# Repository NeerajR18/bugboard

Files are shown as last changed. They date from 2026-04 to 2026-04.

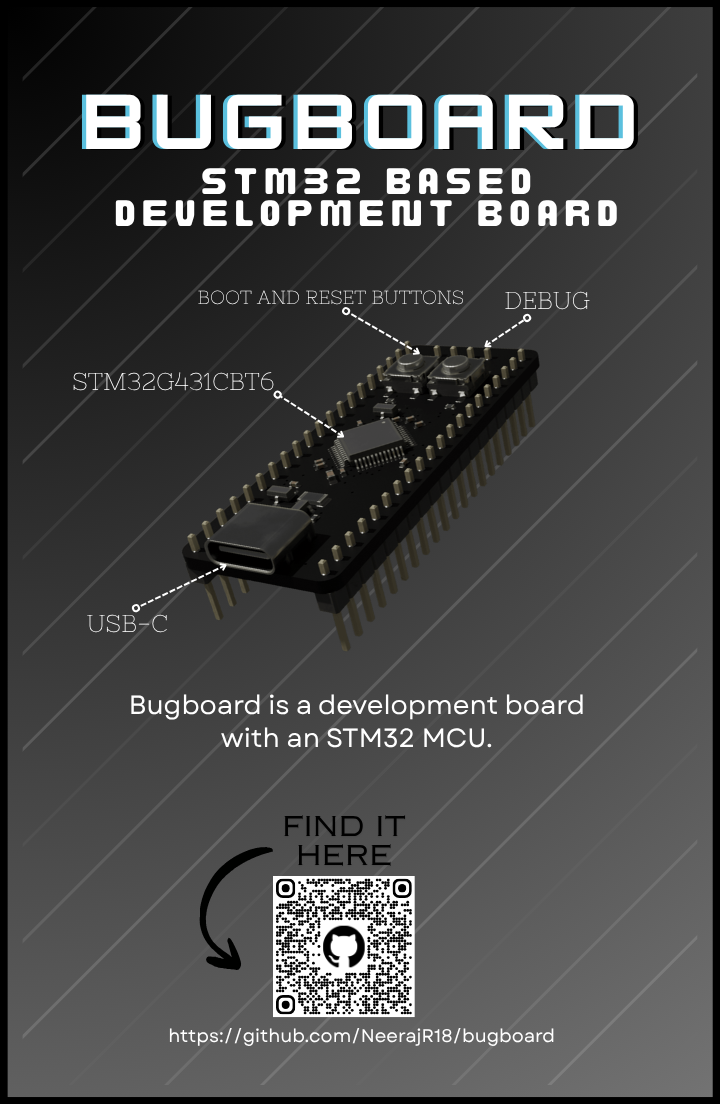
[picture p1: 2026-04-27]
Zine.png

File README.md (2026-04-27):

Zine

# bugboard
STM32 Based Development Board

Note : - This is still a work in progress.

bugboard is a development board with the STM32G431CBT6 as its core. 

This development board is intended to be used in a keyboard PCB. 

# Features

- STM32G431CBT6
- Built-in USB-C Port
- Small size design

# What is a development board?

A development board is a PCB (Printed Circuit Board) with an MCU along with other components such as a USB port, crystals etc. to make prototyping and designing circuits easier.
Since it already has certain components, it can be used directly in many circuits to save cost as well as time.
Development boards can vary in size, components, MCU type, amount of GPIOs etc.

bugboard, has the STM32G431CBT6 as its MCU and was made to be used in a PCB as well as a personal project to learn how to make bigger circuits for me.

# PCB

- Schematic


- PCB

Front


Back


# Images

Blender render of the PCB
Board

BoardB

This project was made using-
- KiCad
- Blender

# Bill Of Materials
|Item |Qty. |Price (USD)|Ext. (USD)|Link |
|---|-----|---|---|---|
| C529355 |  1  |  3.0856 | 3.09 | https://www.lcsc.com/product-detail/C529355.html |
| C105872 | 100 |  0.0009 | 0.09 | https://www.lcsc.com/product-detail/C105872.html |
| C60490 | 100 |  0.0008 | 0.08 | https://www.lcsc.com/product-detail/C60490 |
| C5446 | 5 |  0.1062 | 0.53 | https://www.lcsc.com/product-detail/C5446.html |
| C2765186 | 20  |  0.0617 | 1.23 | https://www.lcsc.com/product-detail/C2765186.html |
| C5180302 | 5 |  0.0403 | 0.2 | https://www.lcsc.com/product-detail/C5180302.html | 
| C60474 | 100 |  0.0010 | 0.1 | https://www.lcsc.com/product-detail/C60474.html |
| C96446 | 20  |  0.0181 | 0.36 | https://www.lcsc.com/product-detail/C96446.html |
| C37704 | 20  |  0.0313 | 0.63 | https://www.lcsc.com/product-detail/C37704.html |
| C720477 | 10  |  0.056 | 0.56 | https://www.lcsc.com/product-detail/C720477.html |

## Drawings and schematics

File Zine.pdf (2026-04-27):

# BBUUGGBBOOAARRDD

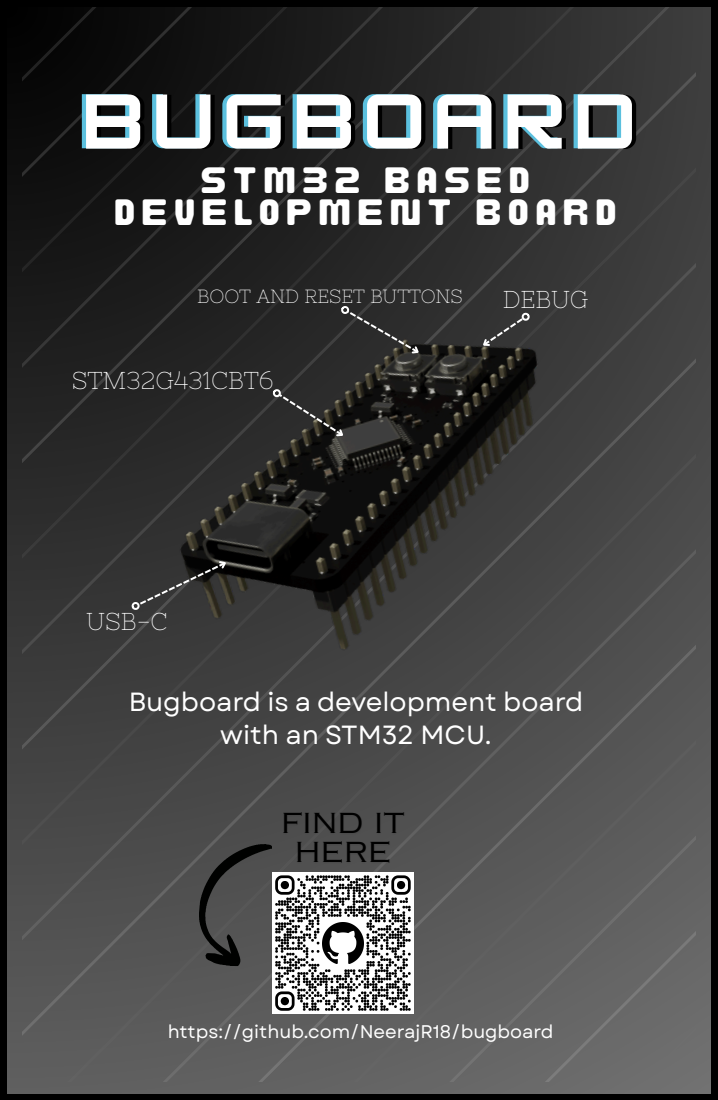
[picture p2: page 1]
S TM3 2 B A S E D D E V E LO PMENT B O A R D; FIND IT HERE; STM32G431CBT6; USB-C; BOOT AND RESET BUTTONS; DEBUG

Bugboard is a development board
with an STM32 MCU.

https://github.com/NeerajR18/bugboard

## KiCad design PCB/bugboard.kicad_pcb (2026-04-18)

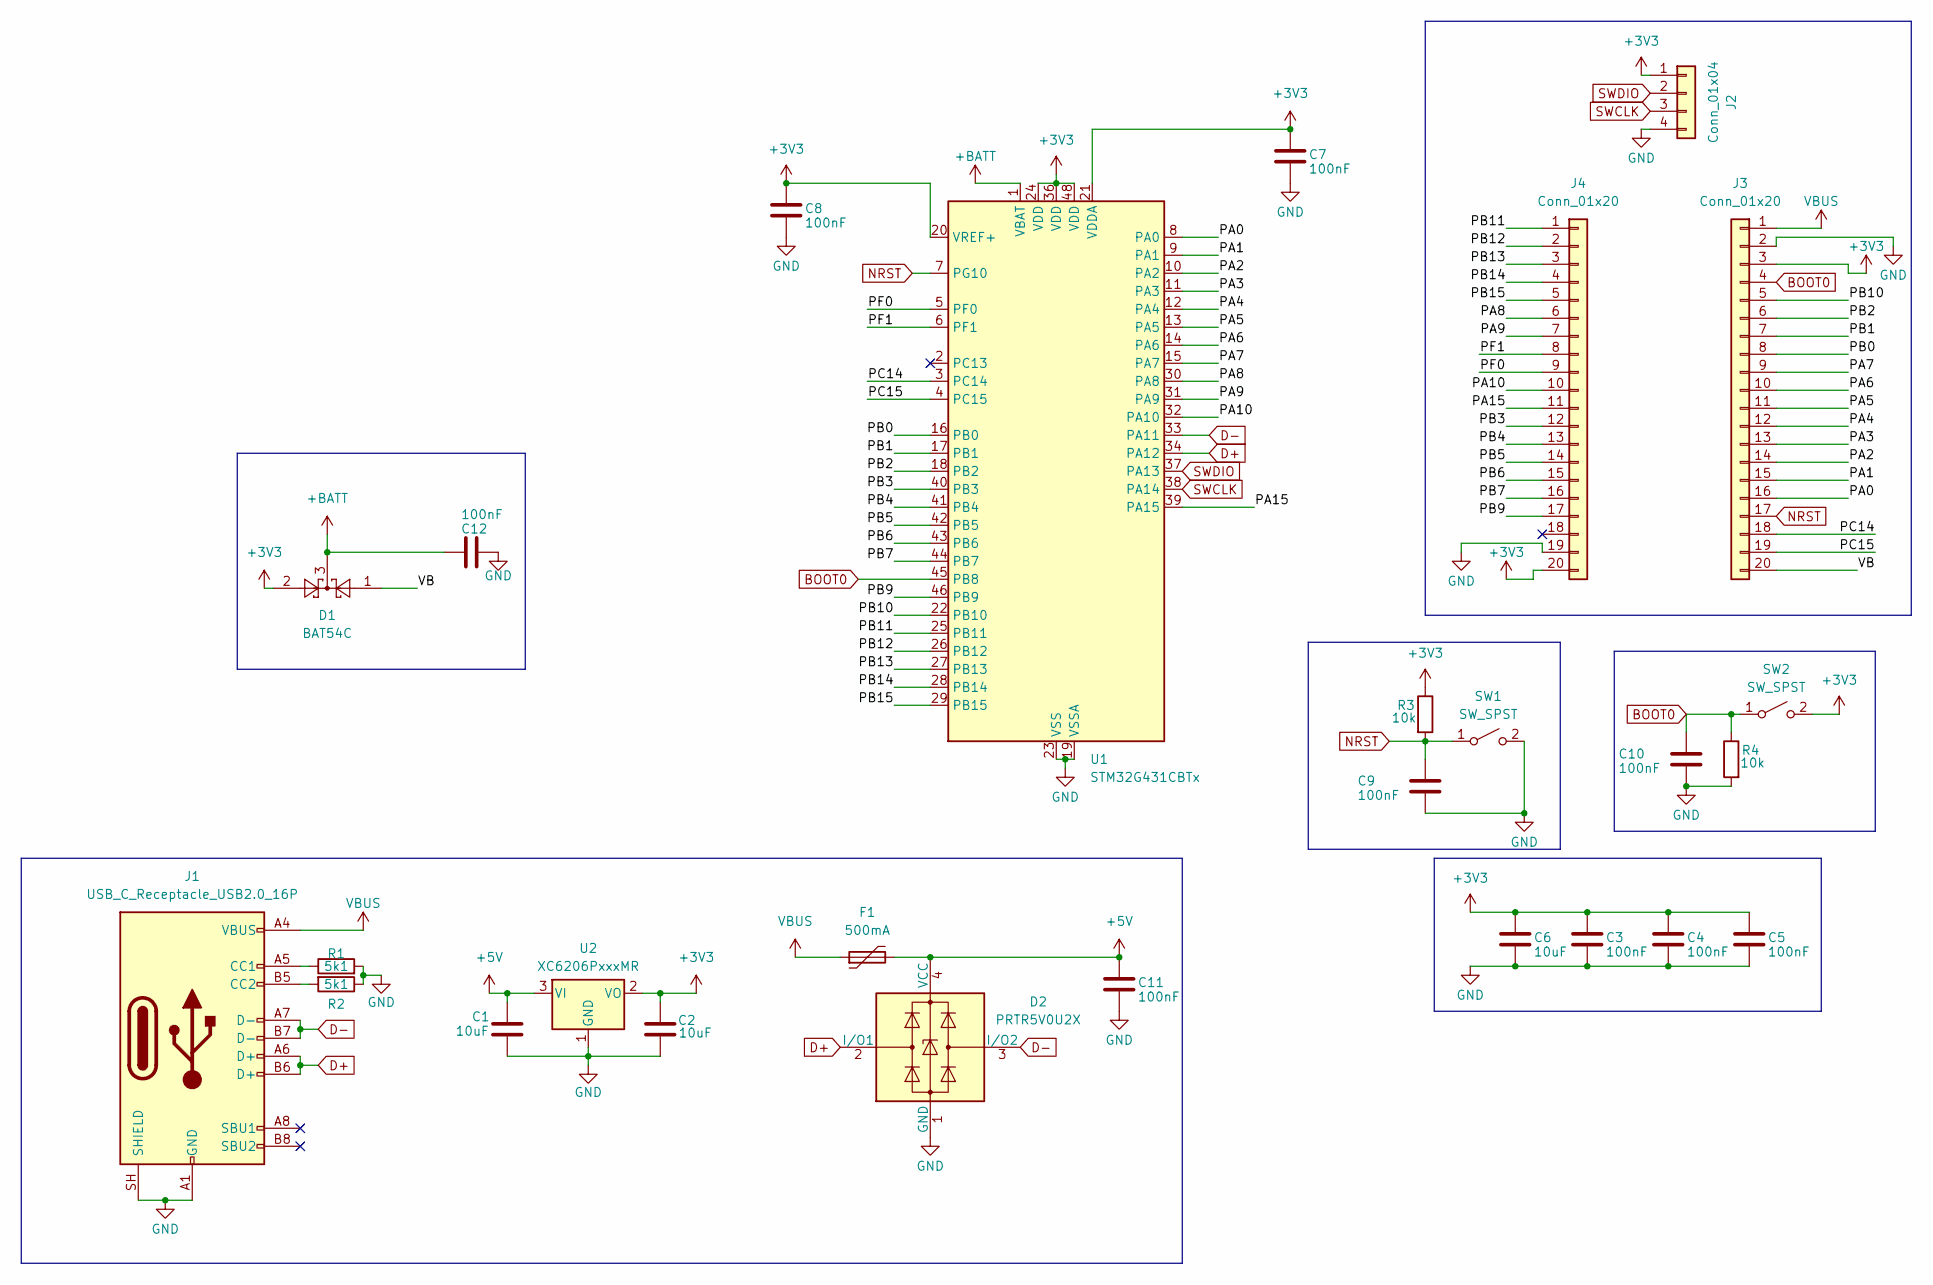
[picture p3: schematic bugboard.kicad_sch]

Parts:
C1, C2: 10uF; C_0402_1005Metric
C3, C4, C5, C7, C8, C9, C10, C11, C12: 100nF; C_0402_1005Metric
C6: 10uF; C_0603_1608Metric
D1: BAT54C; SOT-23
D2: PRTR5V0U2X; SOT-143
F1: 500mA; Fuse_1206_3216Metric
J1: USB_C_Receptacle_USB2.0_16P; USB_C_Receptacle_HRO_TYPE-C-31-M-12
J2: Conn_01x04; PinHeader_1x04_P2.54mm_Vertical
J3, J4: Conn_01x20; PinHeader_1x20_P2.54mm_Vertical
R1, R2: 5k1; R_0402_1005Metric
R3, R4: 10k; R_0402_1005Metric
SW1, SW2: SW_SPST; SW_SPST_TS-1088-xR020
U1: STM32G431CBTx; LQFP-48_7x7mm_P0.5mm
U2: XC6206PxxxMR; SOT-23-3

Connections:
+3V3: C2.2, C3.1, C4.1, C5.1, C6.1, C7.1, C8.1, D1.2, J2.1, J3.3, J4.20, R3.1, SW2.2 (B), U1.20 (VREF+), U1.21 (VDDA), U1.24 (VDD), U1.36 (VDD), U1.48 (VDD), U2.2 (VO)
+5V: C1.1, C11.1, D2.4 (VCC), F1.2, U2.3 (VI)
+BATT: C12.1, D1.3, U1.1 (VBAT)
/PA0: J3.16, U1.8 (PA0)
/PA1: J3.15, U1.9 (PA1)
/PA2: J3.14, U1.10 (PA2)
/PA3: J3.13, U1.11 (PA3)
/PA4: J3.12, U1.12 (PA4)
/PA5: J3.11, U1.13 (PA5)
/PA6: J3.10, U1.14 (PA6)
/PA7: J3.9, U1.15 (PA7)
/PA8: J4.6, U1.30 (PA8)
/PA9: J4.7, U1.31 (PA9)
/PA10: J4.10, U1.32 (PA10)
/PA15: J4.11, U1.39 (PA15)
/PB0: J3.8, U1.16 (PB0)
/PB1: J3.7, U1.17 (PB1)
/PB2: J3.6, U1.18 (PB2)
/PB3: J4.12, U1.40 (PB3)
/PB4: J4.13, U1.41 (PB4)
/PB5: J4.14, U1.42 (PB5)
/PB6: J4.15, U1.43 (PB6)
/PB7: J4.16, U1.44 (PB7)
/PB9: J4.17, U1.46 (PB9)
/PB10: J3.5, U1.22 (PB10)
/PB11: J4.1, U1.25 (PB11)
/PB12: J4.2, U1.26 (PB12)
/PB13: J4.3, U1.27 (PB13)
/PB14: J4.4, U1.28 (PB14)
/PB15: J4.5, U1.29 (PB15)
/PC14: J3.18, U1.3 (PC14)
/PC15: J3.19, U1.4 (PC15)
/PF0: J4.9, U1.5 (PF0)
/PF1: J4.8, U1.6 (PF1)
/VB: D1.1, J3.20
BOOT0: C10.1, J3.4, R4.1, SW2.1 (A), U1.45 (PB8); also elsewhere on the board
D+: D2.2 (I/O1), J1.A6 (D+), J1.B6 (D+), U1.34 (PA12)
D-: D2.3 (I/O2), J1.A7 (D-), J1.B7 (D-), U1.33 (PA11)
GND: C1.2, C2.1, C3.2, C4.2, C5.2, C6.2, C7.2, C8.2, C9.2, C10.2, C11.2, C12.2, D2.1 (GND), J1.A1 (GND), J1.A12 (GND), J1.B1 (GND), J1.B12 (GND), J1.SH (SHIELD), J2.4, J3.2, J4.19, R1.2, R2.1, R4.2, SW1.2 (B), U1.19 (VSSA), U1.23 (VSS), U1.35 (VSS), U1.47 (VSS), U2.1 (GND); also elsewhere on the board
NRST: C9.1, J3.17, R3.2, SW1.1 (A), U1.7 (PG10)
unnamed: J1.A5 (CC1), R1.1
unnamed: J1.B5 (CC2), R2.2
SWCLK: J2.3, U1.38 (PA14)
SWDIO: J2.2, U1.37 (PA13)
VBUS: F1.1, J1.A4 (VBUS), J1.A9 (VBUS), J1.B4 (VBUS), J1.B9 (VBUS), J3.1

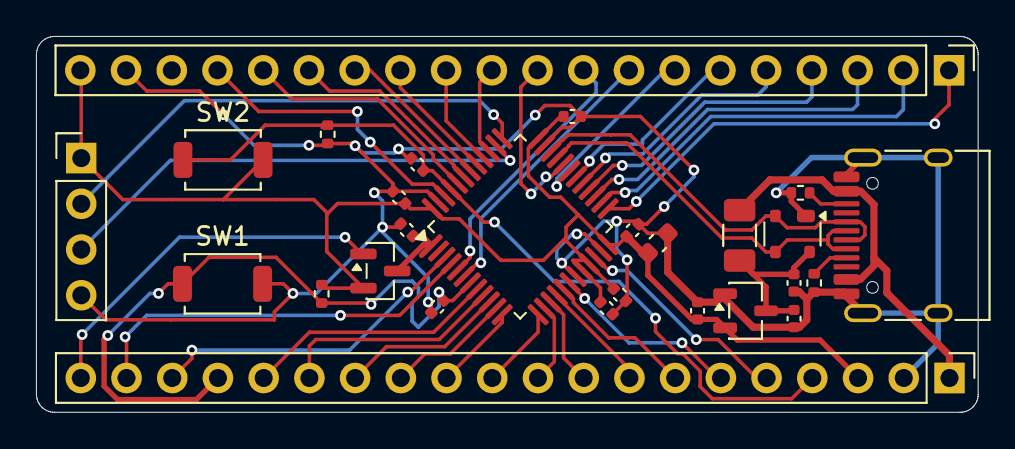
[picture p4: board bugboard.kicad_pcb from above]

Board: 2 copper layers, 52.3 x 20.9 mm, 27 parts (0 on the bottom side), 45 nets.

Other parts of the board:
C17: 100nF; C_0402_1005Metric

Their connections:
BOOT0: C17.1; also elsewhere on the board
GND: C17.2; also elsewhere on the board

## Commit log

2026-04-18 Added PCB and Schematic
    [bugboard.kicad_pcb, bugboard.kicad_sch]
2026-04-18 Updated gerbers
2026-04-18 BOM and Zine added
    [bom.csv]
